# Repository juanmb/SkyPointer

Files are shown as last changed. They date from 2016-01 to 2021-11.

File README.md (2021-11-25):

# SkyPointer

## Description

An open-hardware altazimuth mount with a laser pointer.

The following block diagram shows the current setup:

Block diagram

## CAD

The SkyPointer mechanical parts were designed to be easily fabricated with a 3D
printer. The `cad` folder contains the CAD files in Step, STL and
[FreeCAD](http://www.freecadweb.org) formats.

## Electronics

Circuit schematics and PCB layout were designed with [Kicad](http://kicad.org).
They are stored in the `kicad` folder.

## Arduino

An Arduino Uno board controls two stepper motors (azimuth and elevation) using
a [CNC shield](http://blog.protoneer.co.nz/arduino-cnc-shield/) with some
modifications (documentation in progress).

The Arduino firmware is located in a
[separate repo](https://github.com/davidvg/ArduinoSkyPointer).

## The Python server

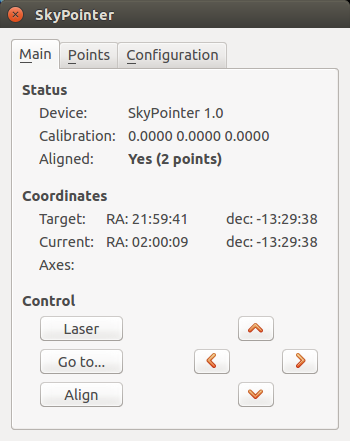
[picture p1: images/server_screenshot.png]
Screenshot of the server GUI


The server receives "goto" messages from
[Stellarium](http://www.stellarium.org/) and sends "current position" packets back.

The Stellarium client-server protocol is documented
[here](http://www.stellarium.org/wiki/index.php/Telescope_Control_%28client-server%29).

### Installing the server in GNU/Linux

Install the required dependencies using your package manager. In Debian/Ubuntu,
you can use apt-get like this

```
$ sudo apt-get install pyqt4-dev-tools python-numpy python-scipy
```

Now you can install the *skypointer* package with pip

```
$ sudo pip install skypointer
```

Alternatively, you can clone this repo and call `setup.py` directly from the
`python` folder

```
$ git clone https://github.com/juanmb/SkyPointer.git
$ cd python
$ python setup.py install
```

For development, it is strongly recommended to install this package into a
[virtual environment](https://virtualenv.pypa.io/en/latest/).

### Installing the server in Windows

Using [Anaconda](https://www.continuum.io/downloads):

```
conda install numpy scipy pyserial pyqt
```

Now you can install the skypointer package using pip

```
$ pip install skypointer
```

### Usage

Run `skypointer-gui`.

### Communication with Stellarium

* Start `skypointer-gui`.

* Check *Enable server* in the *Configuration* tab, select a server port number
  and click *Apply*.

* Start Stellarium.

* Enable the plugin *Telescope control* in Stellarium. If it was disabled,
  you will need to restart Stellarium (only the first time).

* In the configuration window of the *Telescope control* plugin, add a new
  telescope and select the option "External software or a remote computer".

* Choose a name and select "Equinox of the date (JNow)".

* Enter the TCP port of the server.

* Close the dialog and press "Connect".

Now you can send the equatorial coordinates of the selected object in
Stellarium to the *SkyPointer* server by pressing `Ctrl+1`.

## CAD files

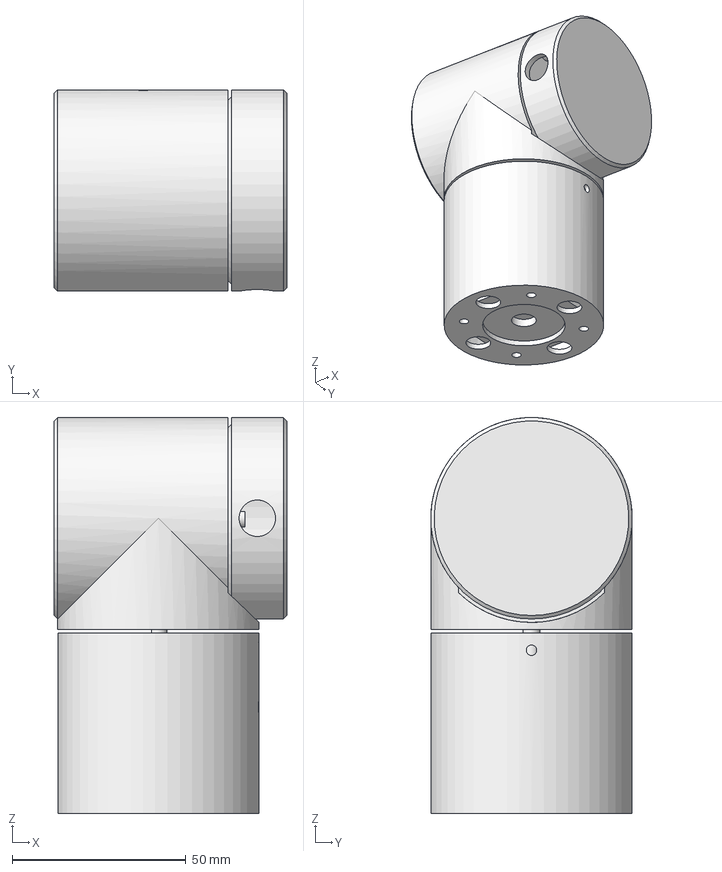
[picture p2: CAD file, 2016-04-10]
cad/skypointer.fcstd
67.0 x 58.0 x 114.0 mm
Azimuth motor
Elevation motor
PCB
Azimuth enclosure
Laser cap
Laser enclosure
Elevation enclosure

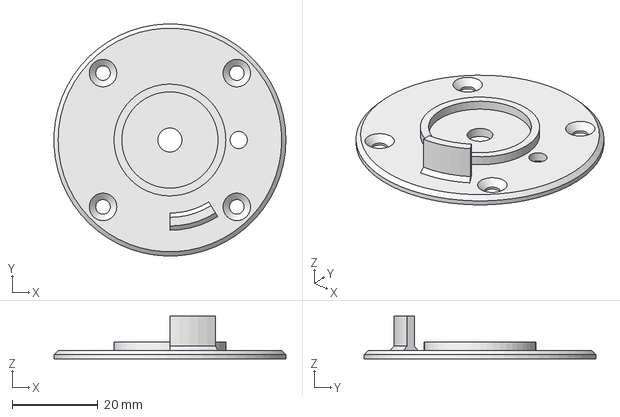
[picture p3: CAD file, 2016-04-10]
cad/laser_cap.step
54.0 x 54.0 x 10.0 mm

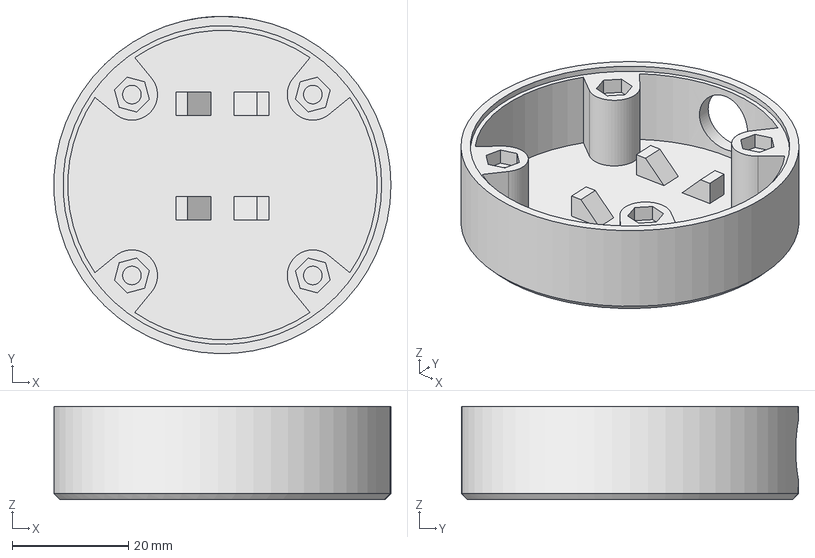
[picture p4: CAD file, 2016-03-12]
cad/laser_enclosure.step
58.0 x 58.0 x 16.0 mm

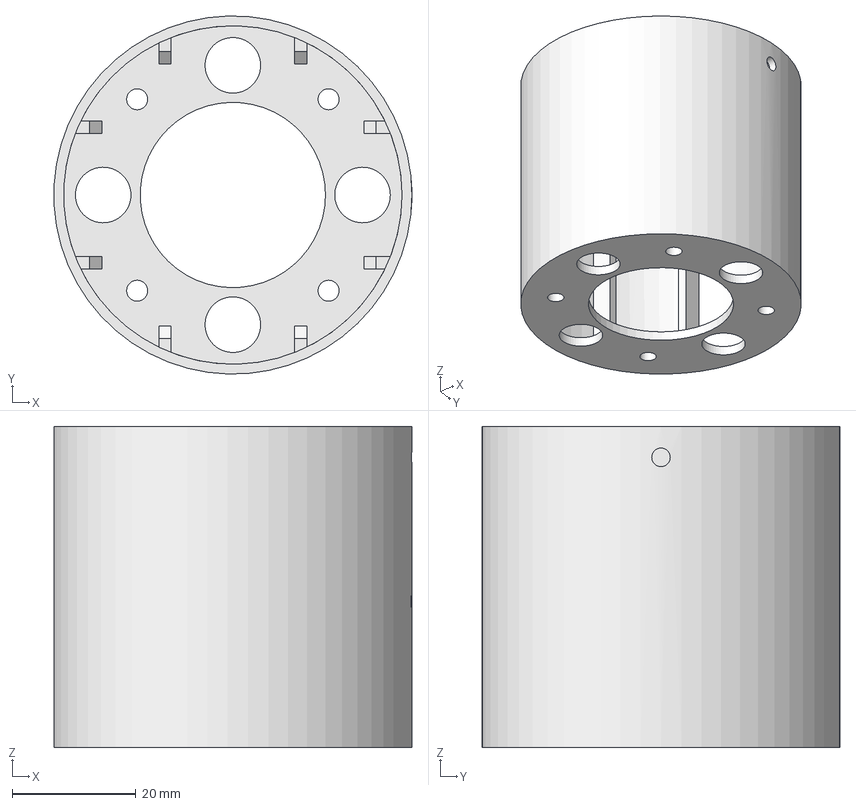
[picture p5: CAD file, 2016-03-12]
cad/azimuth_enclosure.step
58.0 x 58.0 x 52.0 mm

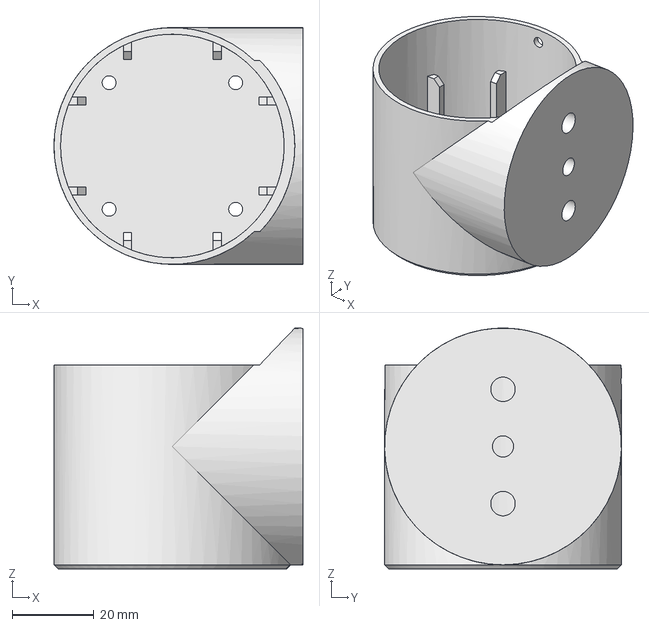
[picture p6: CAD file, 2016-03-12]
cad/elevation_enclosure.step
61.0 x 58.0 x 59.0 mm

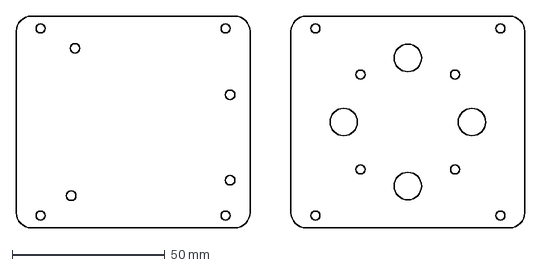
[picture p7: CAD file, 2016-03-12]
cad/arduino_enclosure.dxf
166.6 x 69.3 mm

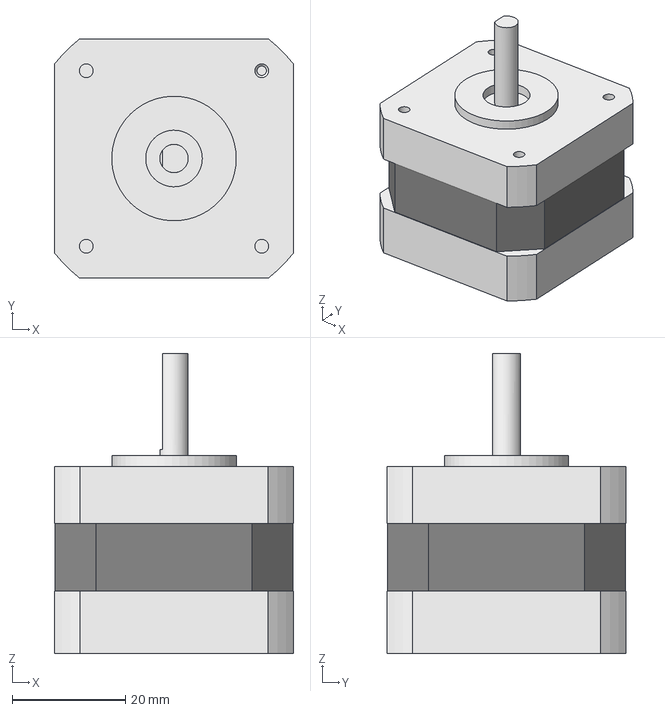
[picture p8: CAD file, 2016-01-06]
cad/NEMA-17_Stepper_Motor_33mm.step
42.3 x 42.3 x 53.0 mm

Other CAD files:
cad/azimuth_enclosure.fcstd
cad/azimuth_enclosure.stl
cad/elevation_enclosure.fcstd
cad/elevation_enclosure.stl
cad/laser_cap.fcstd
cad/laser_cap.stl
cad/laser_enclosure.fcstd
cad/laser_enclosure.stl

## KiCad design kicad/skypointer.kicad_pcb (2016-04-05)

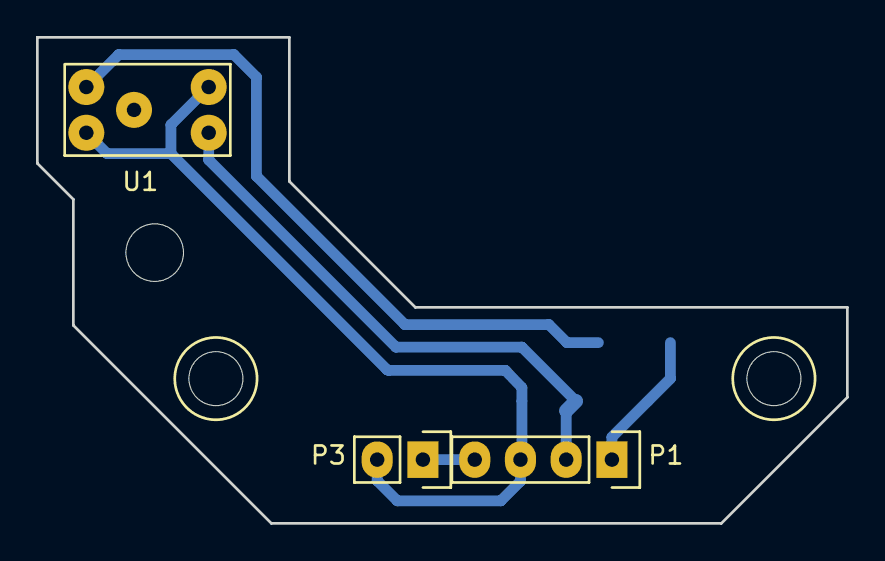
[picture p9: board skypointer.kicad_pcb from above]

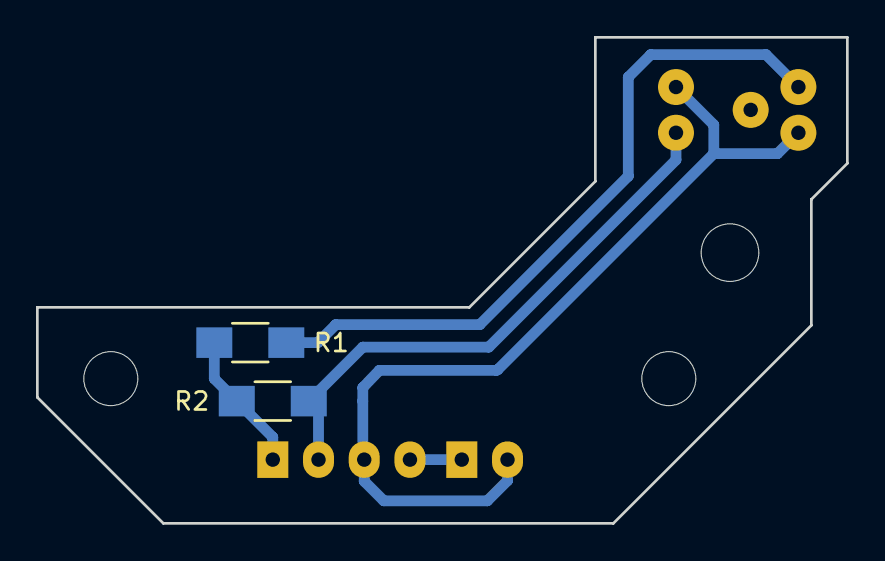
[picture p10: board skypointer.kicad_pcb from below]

Board: 2 copper layers, 45.0 x 27.0 mm, 5 parts (2 on the bottom side), 5 nets.

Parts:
P1: CONN_01X04; Pin_Header_Straight_1x04
P3: Laser; Pin_Header_Straight_1x02
R1: 220; R_1206_HandSoldering
R2: 10k; R_1206_HandSoldering
U1: TCST1230

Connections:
+5V: P1.1, R1.1, R2.1
GND: P1.3, P3.2, U1.2, U1.4
unnamed: P1.2, R2.2, U1.3
unnamed: P1.4, P3.1
unnamed: R1.2, U1.1

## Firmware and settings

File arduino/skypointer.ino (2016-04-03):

/*******************************************************************************
Author: David Vazquez Garcia -- davidvazquez.gijon@gmail.com


The library SkyPointer_MotorShield can be downloaded from:
    https://github.com/davidvg/SkyPointer_MotorShield

*******************************************************************************/

#include <SoftwareSerial.h>
#include <SerialCommand.h>
#include <Wire.h>
#include <SkyPointer_MotorShield.h>
#include <TimerOne.h>
#include <EEPROM.h>

// A modulo operator that handles negative numbers
#define MOD(a,b) ((((a)%(b))+(b))%(b))

// Motor parameters
#define STEPS 200
#define USTEPS 16
#define TOTAL_USTEPS (STEPS*USTEPS)

// Speed parameters
#define DT 10000 // Timer1 interrupt period
//#define RPM 1   // Desired rotation speed in rpm

// Define pins
#define LASER_PIN 13
#define PHOTO_PIN A0

// Define how long the laser stays on when the target has been reached
#define LASER_T_ON 4000000  // 4 seconds

//#define DEBUG_ISR 1  // Variable for Interruption debug
// Pin for DEBUG_ISR
#ifdef DEBUG_ISR
  int blinkLed = 12;
#endif

#define DEBUG_L 1      // Variable for Laser debug
#ifndef DEBUG_ISR      // Check that ISR debug is off
#ifdef DEBUG_L
  int laser_dbg = 12;
#endif
#endif

// Definition of the SerialCommand object
SerialCommand sCmd;
// Definition of the motor shield
SkyPointer_MotorShield MS = SkyPointer_MotorShield();
// Motor 1 on port 1, 200 steps/rev
SkyPointer_MicroStepper *motor1 =MS.getMicroStepper(STEPS, 1);
// Motor 2 on port 2, 200 steps/rev
SkyPointer_MicroStepper *motor2 = MS.getMicroStepper(STEPS, 2);

int home = false;

/****************************************************************************/
// Timing routine
void ISR_timer(){
  // Check if the time the laser has been pointing to the object is equal to
  // the desired ON time
  uint32_t t_on = MS.getTimeOn(); // Get the stored value for laser_t_on
  if (t_on >= LASER_T_ON){
    digitalWrite(LASER_PIN, LOW); // Turn off the laser
    Timer1.detachInterrupt();     // Detach interruption
  }
  MS.setTimeOn(t_on + uint32_t(DT));// Increment with the current time

}


// Interruption routine
void ISR_rotate() {
  #ifdef DEBUG_ISR
    // Turns the LED on when entering the ISR
    // Measures the duration of the interruption routine
    digitalWrite (blinkLed, HIGH);
  #endif

  uint16_t pos, sim_pos, tg;
  uint8_t dir;

  // Turn on the laser
  digitalWrite(LASER_PIN, HIGH);


  sei();  // Enable interrupts --> Serial, I2C (MotorShield)

  // MOTOR 1
  pos = motor1->getPosition();
  // Calculate simmetric point to current position
  sim_pos = (pos + TOTAL_USTEPS/2) % TOTAL_USTEPS;
  tg = motor1->target;

  if (!motor1->isTarget()) {  // Check target has not been reached
    if (pos < TOTAL_USTEPS/2) {
      dir = ((tg > pos) && (tg < sim_pos)) ? FORWARD : BACKWARD;
    } else {
      dir = ((tg > pos) || (tg < sim_pos)) ? FORWARD : BACKWARD;
    }
    motor1->microstep(1, dir);
  }

  // MOTOR 2
  pos = motor2->getPosition();
  // Calculate simmetric point to current position
  sim_pos = (pos + TOTAL_USTEPS/2) % TOTAL_USTEPS;
  tg = motor2->target;

  if (home) {
    // if homing, move motor2 until the photodiode gets interrupted
    if (analogRead(PHOTO_PIN) < 512) {
      motor2->microstep(1, 0);
    } else {
      motor2->setPosition(0);
      home = false;
    }
  } else {
    if (!motor2->isTarget()) {  // Check target has not been reached
      if (pos < TOTAL_USTEPS/2) {
        dir = ((tg > pos) && (tg < sim_pos)) ? FORWARD : BACKWARD;
      } else {
        dir = ((tg > pos) || (tg < sim_pos)) ? FORWARD : BACKWARD;
      }
      motor2->microstep(1, dir);
    }
  }

  // Check if target is reached
  if ((motor1->isTarget()) && (motor2->isTarget())) {
    // If both motors are in the target position...
    Timer1.detachInterrupt();	// Stop Timer1 interruption
    // TURN OFF THE LASER
    //digitalWrite(LASER_PIN, LOW);
    MS.setTimeOn(uint32_t(0));          // Set timer to current time
    Timer1.attachInterrupt(ISR_timer); // Attach temporization routine

    // Must check a global variable that contains the status of the laser, ON
    // or OFF, so the program cannot turn it off if it has been turned on by
    // choice. This variable is not yet defined.
  }

  #ifdef DEBUG_ISR
    digitalWrite (blinkLed, LOW);   // Turn the LED off in ISR exit
  #endif
}

/*******************************************************************************
 * Functions for processing the commands received via serial port
 ******************************************************************************/

// Update the target positions for both motors
void ProcessGoto() {
  uint16_t tgt1, tgt2;

  tgt1 = MOD(atoi(sCmd.next()), TOTAL_USTEPS);
  tgt2 = MOD(atoi(sCmd.next()), TOTAL_USTEPS);

  motor1 -> setTarget(tgt1);
  motor2 -> setTarget(tgt2);

  Serial.print("OK\r");
  Timer1.attachInterrupt(ISR_rotate);  // Enable TimerOne interruption
}


// Move both motors to a relative position
void ProcessMove() {
  uint16_t tgt1, tgt2;

  tgt1 = MOD((int16_t)motor1->getPosition() + atoi(sCmd.next()), TOTAL_USTEPS);
  tgt2 = MOD((int16_t)motor2->getPosition() + atoi(sCmd.next()), TOTAL_USTEPS);

  motor1 -> setTarget(tgt1);
  motor2 -> setTarget(tgt2);

  Serial.print("OK\r");
  Timer1.attachInterrupt(ISR_rotate);  // Enable TimerOne interruption
}


// Stop both motors
void ProcessStop() {
  motor1 -> setTarget(motor1->getPosition());
  motor2 -> setTarget(motor2->getPosition());

  Serial.print("OK\r");
  Timer1.attachInterrupt(ISR_rotate);  // Enable TimerOne interruption
}


// Go to home position (elevation motor only)
void ProcessHome() {
  home = true;
  Serial.print("OK\r");
  Timer1.attachInterrupt(ISR_rotate);  // Enable TimerOne interruption
}


// Get the current position of the motors
void ProcessGetPos() {
  char buf[13];
  uint16_t tgt1, tgt2;

  tgt1 = motor1->getPosition();
  tgt2 = motor2->getPosition();

  sprintf(buf, "P %04d %04d\r", tgt1, tgt2);
  Serial.print(buf);
}


// Enable/disable the laser module
void ProcessLaser() {
  uint8_t enable;

  enable = atoi(sCmd.next()) != 0;
  digitalWrite(LASER_PIN, enable);
  Serial.print("OK\r");
}


// Release motors and shut down laser
void ProcessQuit() {
  motor1->release();
  motor2->release();
  digitalWrite(LASER_PIN, 0);
  Serial.print("OK\r");
}


// Get ID
void ProcessID() {
  Serial.print("SkyPointer 1.0\r");
}


// Write a calibration value (4 bytes) to EEPROM
void ProcessWriteCalib () {
  uint8_t n = atoi(sCmd.next());
  if (n > 3) {
      Serial.print("NK\r");
      return;
  }

  char data[4];
  sscanf(sCmd.next(), "%lx", (uint32_t *)data);
  for (int i = 0; i < 4; i++) {
    EEPROM.write(4*n + i, data[i]);
  }
  Serial.print("OK\r");
}


// Read a calibration value (4 bytes) from EEPROM
void ProcessReadCalib () {
  uint8_t n = atoi(sCmd.next());
  if (n > 3) {
      Serial.print("NK\r");
      return;
  }

  char buf[12], data[4];
  for (int i = 0; i < 4; i++) {
    data[i] = EEPROM.read(4*n + i);
  }
  sprintf(buf, "R %08lx\r", *(uint32_t *)data);
  Serial.print(buf);
}


// Handles unknown commands
void Unrecognized() {
  Serial.print("NK\r");
}
/****************************************************************************/

void setup() {
  // Configure laser pin and set to LOW
  pinMode(LASER_PIN, OUTPUT);
  digitalWrite(LASER_PIN, LOW);
  #ifdef DEBUG_ISR
    pinMode (blinkLed, OUTPUT);
    digitalWrite (blinkLed, LOW);   // Turn off the LED
  #endif

  // Start the serial port
  Serial.begin(115200);

  // Add the commands to the SerialCommand object
  sCmd.addCommand("G", ProcessGoto);    // G pos1 pos2\r
  sCmd.addCommand("M", ProcessMove);    // M steps1 steps2\r
  sCmd.addCommand("S", ProcessStop);    // S\r
  sCmd.addCommand("P", ProcessGetPos);  // P\r
  sCmd.addCommand("H", ProcessHome);    // H\r
  sCmd.addCommand("L", ProcessLaser);   // L enable\r
  sCmd.addCommand("I", ProcessID);      // I\r
  sCmd.addCommand("W", ProcessWriteCalib); // Write calibration value to EEPROM
  sCmd.addCommand("R", ProcessReadCalib);  // Read calibration value from EEPROM
  sCmd.addCommand("Q", ProcessQuit);    // Release motors and shut down laser
  sCmd.addDefaultHandler(Unrecognized);	// Unknown commands

  // Configure interrupt speed (microseconds)
  Timer1.initialize(DT);

  // Start motor shield
  MS.begin();
  //motor1->setSpeed(RPM);
  //motor2->setSpeed(RPM);
}

void loop() {
  sCmd.readSerial();  // Read commands from serial port
}

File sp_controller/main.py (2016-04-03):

import sys
from functools import partial
import glob
import serial
from threading import Timer
from PyQt4 import QtCore, QtGui
from serial import SerialException
from sky_pointer.pointer import Pointer
from sky_pointer.coords import EqCoords
from math import pi, copysign
import main_dlg
import calib_dlg
import goto_dlg
from bright_stars import bright_stars


def list_serial_ports():
    """Lists serial port names"""
    if sys.platform.startswith('win'):
        ports = ['COM%s' % (i + 1) for i in range(256)]
    elif sys.platform.startswith('linux') or sys.platform.startswith('cygwin'):
        # this excludes your current terminal "/dev/tty"
        ports = glob.glob('/dev/tty[A-Za-z]*')
    elif sys.platform.startswith('darwin'):
        ports = glob.glob('/dev/tty.*')
    else:
        raise EnvironmentError('Unsupported platform')

    result = []
    for port in ports:
        try:
            s = serial.Serial(port)
            s.close()
            result.append(port)
        except (OSError, serial.SerialException):
            pass
    return result


class CalibDialog(QtGui.QDialog, calib_dlg.Ui_Dialog):
    def __init__(self, parent=None, calib=(0, 0, 0)):
        super(CalibDialog, self).__init__(parent)
        self.setupUi(self)
        self.z1Value.setValue(calib[0])
        self.z2Value.setValue(calib[1])
        self.z3Value.setValue(calib[2])

    def getCalib(self):
        return self.z1Value.value(), self.z2Value.value(), \
            self.z3Value.value()


class GotoDialog(QtGui.QDialog, goto_dlg.Ui_GotoDialog):
    def __init__(self, parent=None, target=EqCoords(0,0)):
        super(GotoDialog, self).__init__(parent)
        self.setupUi(self)

        by_bayer = sorted(bright_stars, key=lambda l: l[0])
        stars_by_bayer = [''] + [star[0] for star in by_bayer if star[0]]
        self.star_bayer_combo.addItems(stars_by_bayer)

        by_name = sorted(bright_stars, key=lambda l: l[1])
        stars_by_name = [''] + [star[1] for star in by_name if star[1]]
        self.star_name_combo.addItems(stars_by_name)

        self.fillCoords(target)

        self.star_bayer_combo.activated.connect(self.onSelectBayer)
        self.star_name_combo.activated.connect(self.onSelectName)

    def fillCoords(self, coords):
        # fill the values of the coordinate fields
        controls = self.ra_h, self.ra_m, self.ra_s, self.dec_d, self.dec_m, self.dec_s
        for control, v in zip(controls, coords.fields()):
            control.setValue(v)

    def onSelectBayer(self):
        self.star_name_combo.setCurrentIndex(0)
        name = self.star_bayer_combo.currentText()
        star = [star for star in bright_stars if star[0] == name][0]
        self.fillCoords(EqCoords(star[2], star[3]))

    def onSelectName(self):
        self.star_bayer_combo.setCurrentIndex(0)
        name = self.star_name_combo.currentText()
        star = [star for star in bright_stars if star[1] == name][0]
        self.fillCoords(EqCoords(star[2], star[3]))

    def getTarget(self):
        return EqCoords.from_fields(self.ra_h.value(), self.ra_m.value(),
                                    self.ra_s.value(), self.dec_d.value(),
                                    self.dec_m.value(), self.dec_s.value())


class MyApp(QtGui.QDialog, main_dlg.Ui_spcontroller):
    def __init__(self, parent=None):
        super(MyApp, self).__init__(parent)
        self.setupUi(self)
        self.cfg = QtCore.QSettings('skypointer')
        self.run_tmr = Timer(0, None)

        # allow using the arrows keys
        self.setChildrenFocusPolicy(QtCore.Qt.NoFocus)

        # bind signals
        self.applyButton.clicked.connect(self.onApply)
        self.laserButton.clicked.connect(self.onLaser)
        self.upButton.pressed.connect(partial(self.onArrow, 'up', True))
        self.upButton.released.connect(partial(self.onArrow, 'up', False))
        self.downButton.pressed.connect(partial(self.onArrow, 'down', True))
        self.downButton.released.connect(partial(self.onArrow, 'down', False))
        self.leftButton.pressed.connect(partial(self.onArrow, 'left', True))
        self.leftButton.released.connect(partial(self.onArrow, 'left', False))
        self.rightButton.pressed.connect(partial(self.onArrow, 'right', True))
        self.rightButton.released.connect(partial(self.onArrow, 'right', False))
        self.gotoButton.clicked.connect(self.onGoto)
        self.alignButton.clicked.connect(self.onAlign)
        self.calibrateButton.clicked.connect(self.onCalibrate)

        for port in list_serial_ports():
            self.serialCombo.addItem(port)

        # load settings
        idx = self.serialCombo.findText(self.cfg.value('serial_port', type=str))
        self.serialCombo.setCurrentIndex(idx)
        idx = self.joystickCombo.findText(self.cfg.value('joystick', type=str))
        self.joystickCombo.setCurrentIndex(idx)
        self.enableServer.setChecked(self.cfg.value('enable_server', type=bool))
        self.localHostOnly.setChecked(self.cfg.value('localhost_only', type=bool))
        self.serverPort.setValue(self.cfg.value('server_port', type=int))

        self.connect_pointer()

    def setChildrenFocusPolicy (self, policy):
        def set_policy (parentQWidget):
            for childQWidget in parentQWidget.findChildren(QtGui.QWidget):
                childQWidget.setFocusPolicy(policy)
                set_policy(childQWidget)
        set_policy(self)

    def connect_pointer(self):
        if hasattr(self, 'ptr'):
            self.ptr.close()

        try:
            self.ptr = Pointer(str(self.cfg.value('serial_port', type=str)))
        except (SerialException, IOError) as e:
            self.statusDevice.setText('None')
            QtGui.QMessageBox.warning(self, "Serial error", str(e))
            self.ptr = None
        else:
            self.statusDevice.setText(self.ptr.get_id())
            self.update_calib()

        self.statusAligned.setText('No')
        self.coordBox.setEnabled(self.ptr is not None)
        self.controlBox.setEnabled(self.ptr is not None)

    def update_target(self):
        if self.ptr:
            tgt = self.ptr.target
            self.coordTarget.setText(str(tgt))
            self.alignButton.setEnabled(True)

    def update_calib(self):
        if self.ptr:
            calib = self.ptr.calib
            self.statusCalibration.setText(' '.join([("%.4f" % c) for c in calib]))
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

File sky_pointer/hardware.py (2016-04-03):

#!/usr/bin/env python

import time
import serial
import struct
import threading

STEPS = 3200    # Number of microsteps per revolution of the motors
NRETRIES = 3    # Number of retries when sending a serial command


class Hardware:
    """Serial communication with SkyPointer board."""

    def __init__(self, device='/dev/ttyUSB0', baud=115200):
        self.__lock = threading.Lock()
        self.__ser = serial.Serial(device, baud, timeout=1)
        self.__ser.flushInput()
        time.sleep(1.5)

    def __send_command(self, cmd, ret_len=3, ret_ok='OK'):
        """Send a serial command and check the response."""
        with self.__lock:
            for i in range(NRETRIES):
                self.__ser.write(cmd + '\r')
                ret = self.__ser.read(ret_len)

                if ret.startswith(ret_ok):
                    return ret
                print "command failed. retrying"
                self.__ser.flushInput()

        raise IOError('Serial command "%s" returned "%s"' % (cmd, ret.strip()))

    def get_id(self):
        return self.__send_command('I', ret_len=15, ret_ok='SkyPointer')

    def enable_laser(self, enable):
        self.__send_command('L %d' % int(enable))

    def goto(self, ha, el):
        self.__send_command('G %d %d' % (ha, el))

    def move(self, ha, el):
        self.__send_command('M %d %d' % (ha, el))

    def stop(self):
        self.__send_command('S')

    def home(self):
        self.__send_command('H')

    def get_pos(self):
        ret = self.__send_command('P', ret_len=12, ret_ok='P ')
        ha, el = ret.strip().split()[1:3]
        return int(ha), int(el)

    def get_calib(self, n):
        ret = self.__send_command('R %d' % n, ret_len=11, ret_ok='R ')
        v = int(ret.strip().split()[1], 16)
        cal = struct.unpack('!f', struct.pack('!I', v))[0]
        return cal if abs(cal) < 1. else 0.0

    def set_calib(self, n, val):
        v = struct.unpack('!I', struct.pack('!f', val))[0]
        self.__send_command('W %d %x' % (n, v))

    def close(self):
        # reset the Arduino before closing the port
        self.__ser.setDTR(False)
        time.sleep(0.05)
        self.__ser.setDTR(True)
        self.__ser.close()

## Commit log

2015-05-08 Fix two (copy-paste) bugs. Add some info to README.md
    [main.py]
2015-09-19 Read hardware ID. Fix some bugs
    [coords.py, gamepad.py, hardware.py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]
2015-10-04 Improve the pointing model. Add script for calculating mount errors
    [coords.py, gamepad.py, hardware.py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]
2015-10-08 Fix some stupid bugs. Increase verbosity of log messages
    [gamepad.py, pointer.py, pointing_model.py]
2015-11-07 Retry and flush the buffer when a serial cmd fails
    [gamepad.py, hardware.py]
2015-11-07 Calculate pointing errors reading observations from a file
    [calc_pointer_errors.py, main.py]
2016-01-06 Add CAD files
    [NEMA-17_Stepper_Motor_33mm.step, azimuth_enclosure.fcstd, azimuth_enclosure.step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]
2016-01-10 File arduino/skypointer.ino added. It includes the Arduino code for the SkyPointer.
2016-01-12 Adjust dimensions in CAD files
    [azimuth_enclosure.fcstd, azimuth_enclosure.step, azimuth_enclosure.stl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]
2016-01-18 Add Kicad files
    [skypointer.fcstd, skypointer.kicad_pcb, skypointer.sch]
2016-02-28 Read and write calibration values to EEPROM
2016-03-06 Add a MOSFET to the PCB
    [skypointer.kicad_pcb, skypointer.sch]
2016-03-09 Modify some mechanical dimensions. Add Arduino enclosure
    [arduino_enclosure.dxf, azimuth_enclosure.fcstd, azimuth_enclosure.step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]
2016-03-12 Update mechanical parts
    [arduino_enclosure.dxf, azimuth_enclosure.fcstd, azimuth_enclosure.step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]
2016-03-28 Fix pcb dimensions
    [skypointer.kicad_pcb]
2016-04-03 Add skypointer_motorshield Arduino library
2016-04-04 Remove MOSFET from PCB
    [skypointer.kicad_pcb, skypointer.sch]
2016-04-05 Makefile added to /arduino and .gitignore updated to ignore Arduino's build directory.
2016-04-09 Different pins for N and P-channel Mosfets. Makefile updated. gitignore updated with .swp files.
2016-04-09 Fix installation error. Send the current position back to Stellarium
    [main.py, pointer.py, protocol.py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]
2016-04-10 Update CAD models
    [laser_cap.fcstd, laser_cap.step, laser_cap.stl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]
2016-04-14 Function SkyPointer_MotorShieild::laser() turns the laser on and off, setting the appropiate pin depending on the type of MOSFET. Comments cleanup.
2016-12-14 Fix a compatibility issue with QT library
    [main.py, server.py]
2016-12-15 Remove Arduino firmware. Update README
2021-11-08 Update README.md
    https://forum.kicad.info/t/warning-avoid-all-links-to-kicad-pcb-org-use-kicad-org/31521
